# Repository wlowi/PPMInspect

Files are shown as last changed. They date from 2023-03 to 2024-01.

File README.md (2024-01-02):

# PPMInspect

Ein Tool zur Analyse von PPM Signalen.  

## Features

- PPM Decoder bis 16 Kanäle mit Anzeige der Timing Werte für jeden Kanal
- PWM Decoder
- Einfaches Voltmeter
- Oszilloskop mit 1kHz bis 100kHz Samplingrate
- Trigger (Freilaufend, ansteigende Flanke, abfallende Flanke)
- Zuschaltbares oversampling
- Einstellbarer Triggerlevel
- Triggerverzögerung bis 9900 Microsekunden.

Zur [Bedienungsanleitung](MANUAL.md)

## Handware

- 1 Arduino Nano
- 1 OLED Display 1.3" (SH1106 Controller)
- 3 Taster (RAFI Kurzhubtaster RACON 8 mit Stößel 7.5mm Höhe 8.2mm)
- 1 Z-Diode 4.7V
- 3 Widerstände 1/8 W 47k
- 2 Widerstände 1/8 W 100k
- 1 Elko 100uF 16V
- Stecker nach Wahl (Gebogene Pfostenleiste)

## Verwendete Libraries

Folgende Libraries werden benötigt und über die Arduino IDE installiert:

- SSD1306Ascii

## Arduino Nano Ports

- LCD SCK:   A5 (Port PC5 SCL)
- LCD SDA:   A4 (Port PC4 SDA)
- Taster 1:   5 (Port PD5 PCINT21 PCI2)
- Taster 2:   6 (Port PD6 PCINT22 PCI2)
- Taster 3:   7 (Port PD7 PCINT23 PCI2)
- Analog In: A3 (Port PC3)
- PPM In:     8 (Port PB0 ICP1)
- Vcc:       A0
   
## Timer

- Timer 0:     8 bit       Arduino micros() millis() delay()...
- Timer 1:    16 bit       PPM Timing (See PPM.cpp)

## Verzeichnisse

CAD - dxf und FreeCAD Model für ein Gehäuse  
doc - Zur Dokumentation  
PCB - KiCAD Schaltplan und Platinenlayout  
PPMGenerate_DELAY - PPM Test Generator mit Verzögerungsschleife  
PPMGenerate_ISR - PPM Test Generator über Interrupts  
PPMGenerate_PWM - PPM Test Generator über Hardware-PWM  
PPMInspect - Der Source Code  

## Und Sonst...

### Wird anstelle eines SH1106 ein SSD1306 Display Controller verwendet muss in PPMInspect.ino Zeile 98 von:

textUI.setDisplay(new TextUILcdSSD1306( &SH1106_128x64 )); \
geändert werden in: \
textUI.setDisplay(new TextUILcdSSD1306( &Adafruit128x64 ));

### Genauigkeit PPM Scan

- Servotiming pro Kanal: +/- 1 Microsekunde
- Puls: +/- 1 Microsekunde
- Frame: +/- 1 Microsekunde

## TODO

- Nix zur Zeit

## History

0.10.0: PWM Decoder\
0.9.17: User Interface aktualisiert\
0.9.16: PPM Erzeugung verbessert\
0.9.15: Frame Genauigkeit verbessert\
0.9.14: Min/max Werte im Voltmeter

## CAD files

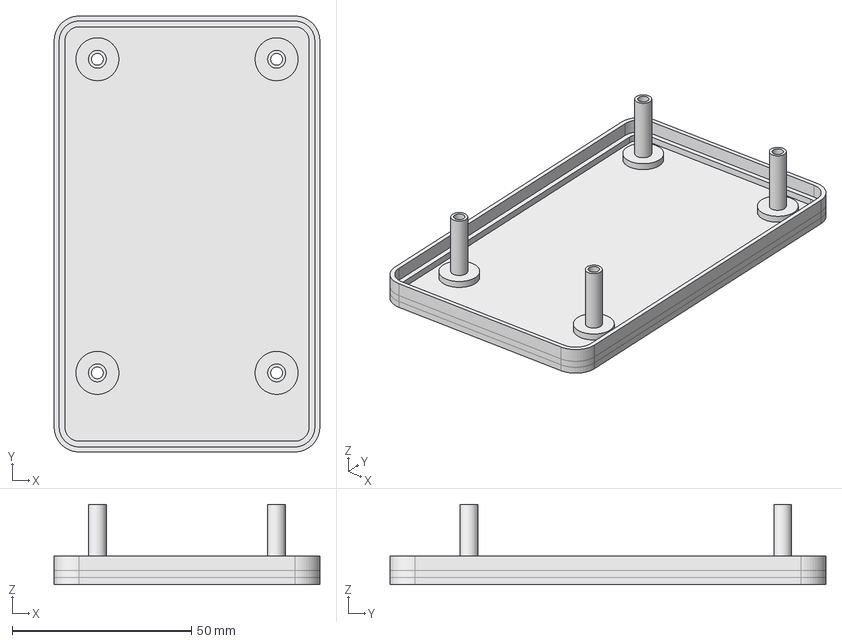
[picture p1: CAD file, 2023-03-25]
CAD/PPMInspectUnterschale.FCStd
74.1 x 121.7 x 22.4 mm

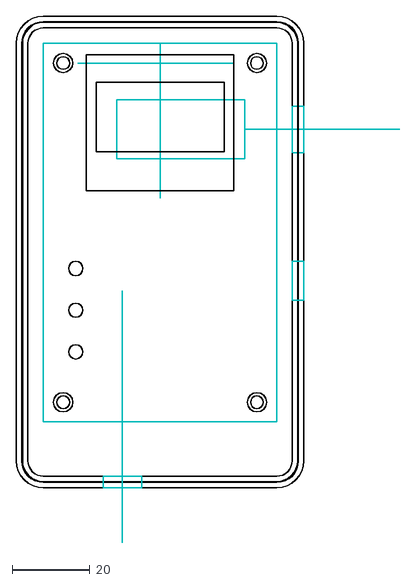
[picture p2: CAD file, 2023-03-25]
CAD/PPMInspect.dxf
98.9 x 135.8

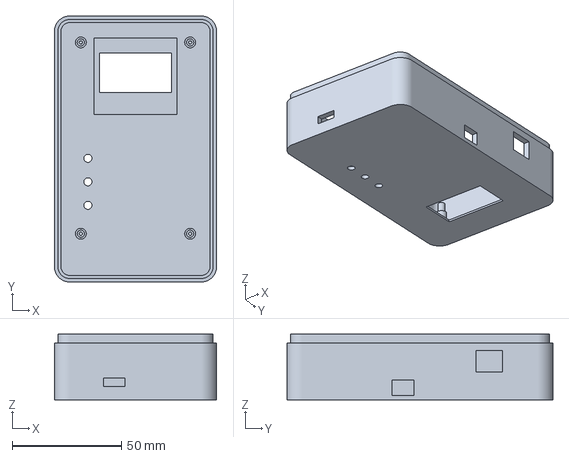
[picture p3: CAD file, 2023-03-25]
CAD/PPMInspectOberschale-Body.3mf
74.1 x 121.7 x 30.0 mm

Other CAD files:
CAD/PPMInspectUnterschale-Body.3mf
CAD/PPMInspectOberschale.FCStd
CAD/PPMInspectOberschale-Body.stl
CAD/PPMInspectUnterschale-Body.stl

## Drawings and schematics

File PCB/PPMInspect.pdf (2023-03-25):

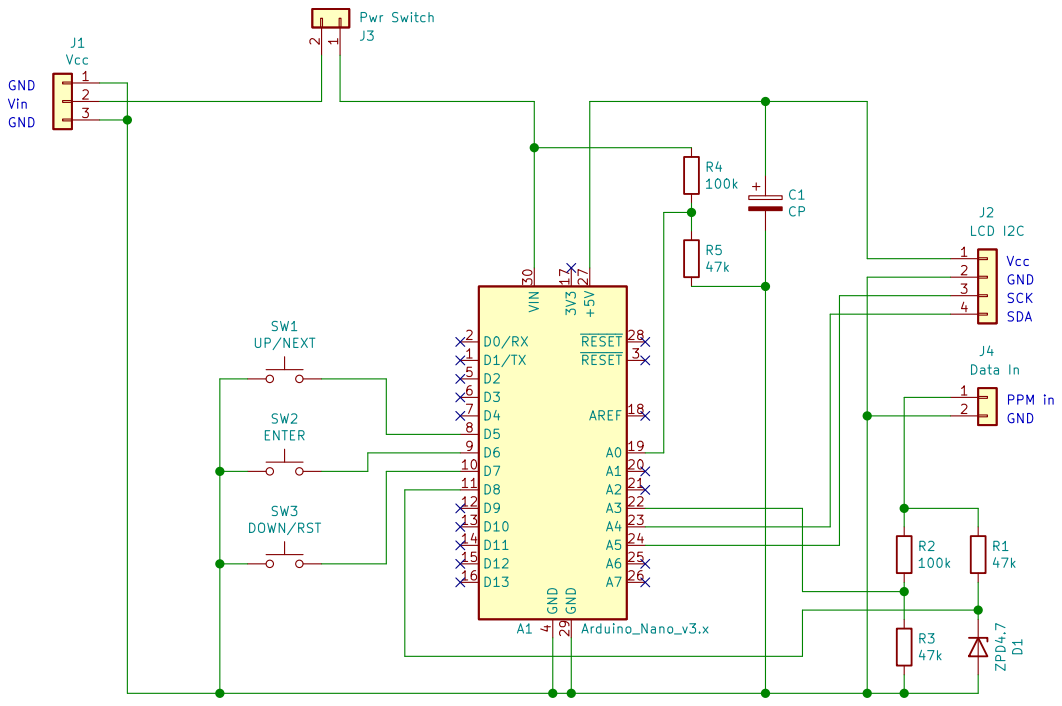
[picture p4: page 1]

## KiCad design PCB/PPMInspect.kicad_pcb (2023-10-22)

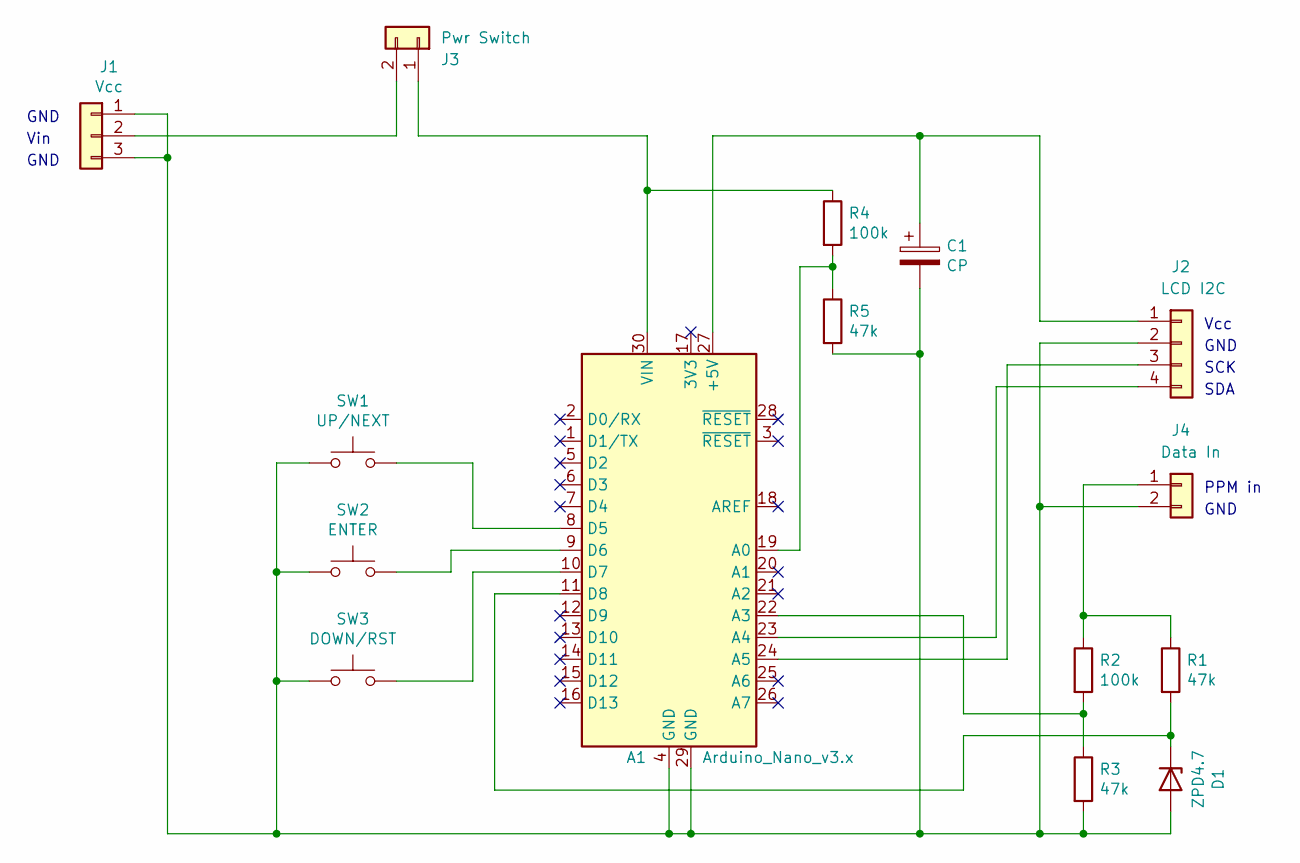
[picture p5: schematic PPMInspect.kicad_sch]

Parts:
A1: Arduino_Nano_v3.x; Arduino_Nano
C1: CP; CP_Radial_D6.3mm_P2.50mm
D1: ZPD4.7; D_DO-35_SOD27_P10.16mm_Horizontal
J1: Vcc; PinHeader_1x03_P2.54mm_Horizontal
J2: LCD I2C; PinSocket_1x04_P2.54mm_Vertical
J3: Pwr Switch; PinHeader_1x02_P2.54mm_Horizontal
J4: Data In; PinHeader_1x02_P2.54mm_Horizontal
R1, R3, R5: 47k; R_Axial_DIN0207_L6.3mm_D2.5mm_P10.16mm_Horizontal
R2, R4: 100k; R_Axial_DIN0207_L6.3mm_D2.5mm_P10.16mm_Horizontal
SW1: UP/NEXT; SW_PUSH_6mm
SW2: ENTER; SW_PUSH_6mm
SW3: DOWN/RST; SW_PUSH_6mm

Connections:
unnamed: A1.8 (D5), SW1.2
unnamed: A1.9 (D6), SW2.2
unnamed: A1.10 (D7), SW3.2
unnamed: A1.11 (D8), D1.1 (K), R1.2
unnamed: A1.19 (A0), R4.2, R5.1
unnamed: A1.22 (A3), R2.2, R3.1
unnamed: A1.23 (A4), J2.4
unnamed: A1.24 (A5), J2.3
unnamed: A1.27 (+5V), C1.1, J2.1
unnamed: A1.4 (GND), A1.29 (GND), C1.2, D1.2 (A), J1.1, J1.3, J2.2, J4.2, R3.2, R5.2, SW1.1, SW2.1, SW3.1
unnamed: A1.30 (VIN), J3.1, R4.1
unnamed: J1.2, J3.2
unnamed: J4.1, R1.1, R2.1

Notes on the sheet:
SDA
Vin
SCK
GND
PPM in
Vcc

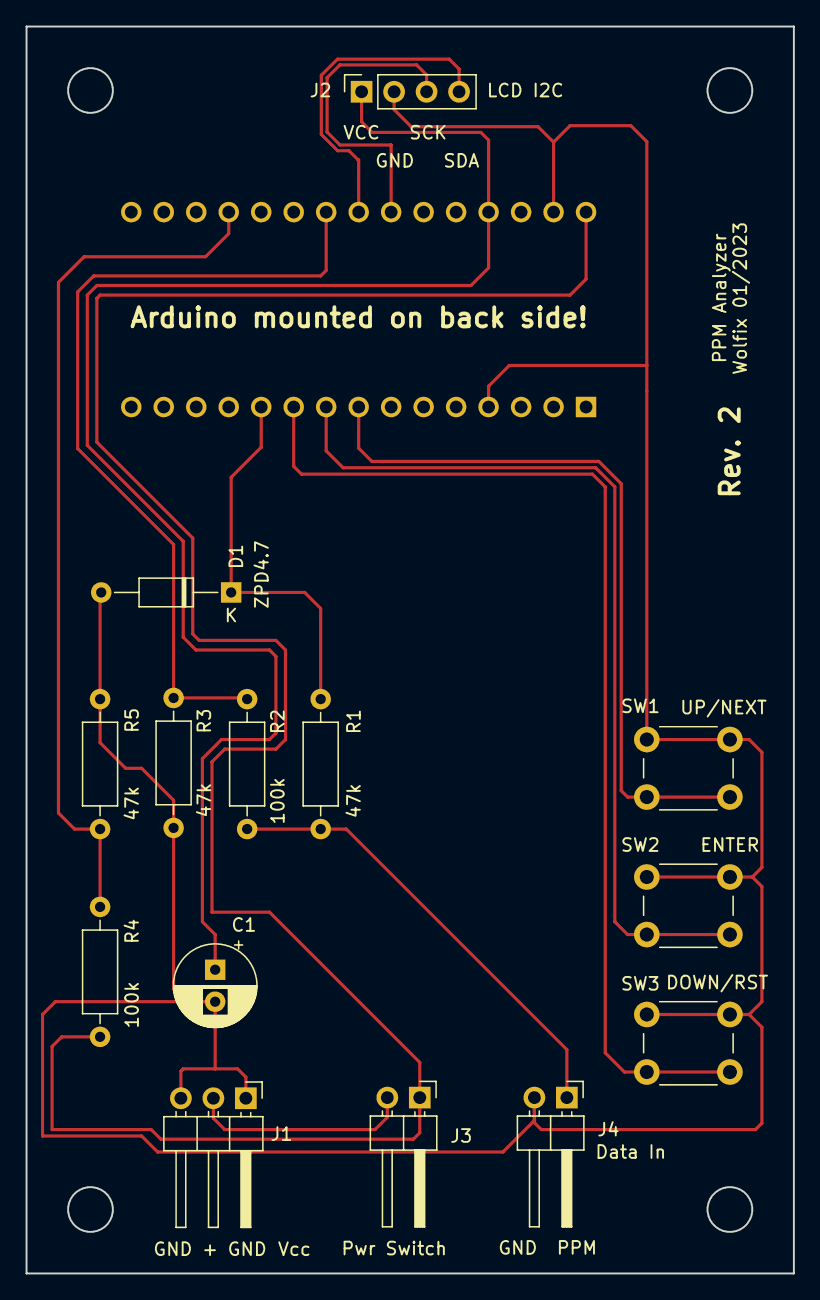
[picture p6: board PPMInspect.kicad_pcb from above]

Board: 2 copper layers, 60.0 x 97.5 mm, 15 parts (1 on the bottom side), 13 nets.

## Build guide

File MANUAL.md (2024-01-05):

# PPMInspect

Diese Anleitung beschreibt PPMInspect 0.10.3 (Januar 2024)

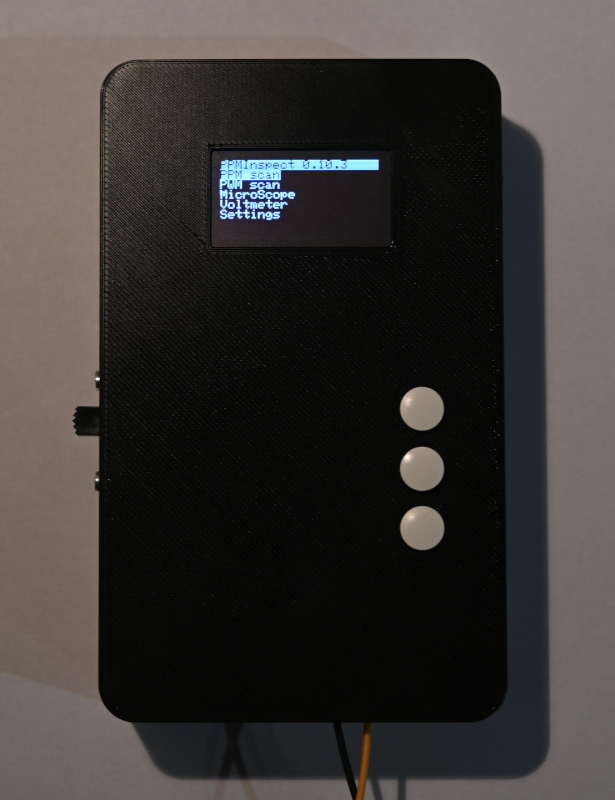
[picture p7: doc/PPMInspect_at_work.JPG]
AtWork


---
## Grundsätzliche Bedienung

Die Bedienung erfolgt über 3 Taster.
Die Taster unterscheiden einen kurzen und einen langen (> 250 MilliSekunden) Tastendruck. \
Wird der Taster länger als 1 Sekunde gedrückt gehalten wird die Funktion eines kurzen Tastendrucks automatisch wiederholt.

Taster 1:
- kurz:   UP
- lang:   RESET

Taster2:
- kurz:   ENTER
- lang:   CLEAR

Taster3:
- kurz:   DOWN
- lang:   OPTION

Seit Version 0.9.15 wird die Versorgungsspannung überwacht.\
Fällt die Spannung unter den in den Einstellungen eingestellten Wert, so wird im Display periodisch "Low Bat" angezeigt.

---
## Funktionstasten übersicht

### PPM Scan

- UP: Vorherige Zeile
- RESET: Sampling neu starten

- ENTER: Zur Kanalanzeige
- CLEAR: Zum Hauptmenü

- DOWN: Nächste Zeile
- OPTION: - 

### PPM Scan Kanalanzeige

- UP: Vorherige Zeile
- RESET: -

- ENTER: Zum PPM Scan
- CLEAR: Zum PPM Scan

- DOWN: Nächste Zeile
- OPTION: -

### PWM Scan

- UP: Vorherige Zeile
- RESET: Sampling neu starten

- ENTER: Zur grafischen PWM Anzeige
- CLEAR: Zum Hauptmenü

- DOWN: Nächste Zeile
- OPTION: -

### Grafische PWM Anzeige

- UP: Zum PWM Scan
- RESET: Wechsel "Servo" / "%" Modus

- ENTER: -
- CLEAR: Zum PWM Scan

- DOWN: Anzeige einfrieren
- OPTION: Gitter aus/ein

### MicroScope

- UP: Zum Hauptmenü
- RESET: -

- ENTER: MicroScope Einstellungen
- CLEAR: Zum Hauptmenü

- DOWN: Anzeige einfrieren
- OPTION:  Gitter aus/ein

### Voltmeter

- UP: Zum Hauptmenü
- RESET: Minimum/Maximum zurücksetzen

- ENTER: Zum Hauptmenü
- CLEAR: Zum Hauptmenü

- DOWN: Minimum/Maximum Ein/Aus
- OPTION: -

### Settings

- UP: Vorherige Zeile
- RESET: -

- ENTER: Einstellung ändern
- CLEAR: -

- DOWN: Nächste Zeile
- OPTION: -

---
## Funktionen

Im Hauptmenü wird die Funktion mit UP / DOWN ausgewählt und mit ENTER aufgerufen.

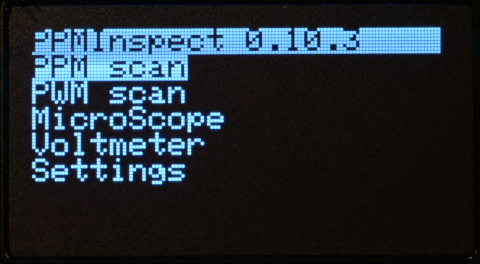
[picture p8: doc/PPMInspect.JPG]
Homescreen


---
## PPM Scan

Der PPM Scanner synchronisiert sich auf ein PPM Signal und zeigt die Signal Parameter an.

- Frame: Die Frame Länge in Microsekunden. Minimum und Maximum.
- Pulse: Die Pulslänge die jeden Kanal einleitet. Jeweils Minimum und Maximum, sowie die Puls Polarität.
- Level: Den Spannungslevel für LOW und HIGH in Volt.
- Frames: Die Anzahl der dekodierten Frames.

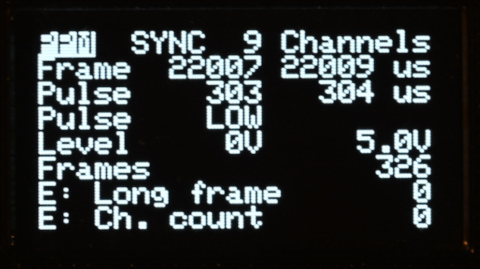
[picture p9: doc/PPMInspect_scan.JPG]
SCAN Scan


Mit CLEAR (langer Druck auf die ENTER Taste) wird in das Hauptmenu zurück gesprungen.

Mit RESET (langer Druck auf die UP Taste) werden alle Werte zurück gesetzt und neu synchronisiert.\
Mit der DOWN Taste kann nach unten gescrollt und weitere Parameter angezeigt werden.

- E: Long frames: Zu lange (verlorene) Frames
- E: Ch. count: Falsche Anzahl an Kanälen
- E: Pulse time: Puls Timing ausserhalb der Spezifikation (Siehe Einstellungen)

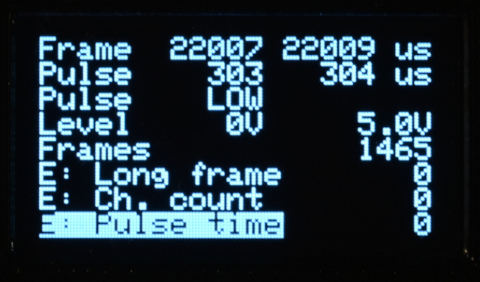
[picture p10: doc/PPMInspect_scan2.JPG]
SCAN Scan


Ein kurzer Druck auf ENTER wechselt zur Kanal Anzeige.\
Hier wird für jeden Kanal der letzte, der minimale und der maximale Timing Wert in Microsekunden angezeigt.\
Ein weiterer Druck auf ENTER wechselt zurück in die Scan Anzeige.

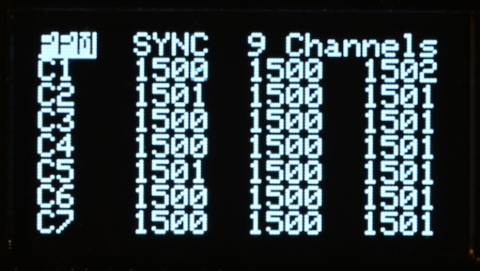
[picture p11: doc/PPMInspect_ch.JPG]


---
## PWM Scan

Der PWM Scanner zeigt die Eigenschaften einen PWM Signals an.

- Cyc.: Zykluszeit (H Puls + L Puls) in Microsekunden. Minimum und Maximum. 
- Pulse L: Zeit des letzten L Pulses.
- Pulse H: Zeit des letzten H Pulses.
- Duty Cyc.: Duty cycle. Prozentsatz des H Pulses an der Gesamtzeit.
- Freq.: Aktuelle PWM Frequenz
- Frames: Anzahl gescannter Frames
- Miss: Timer Überlauf. Kein Puls für 32 Millisekunden.

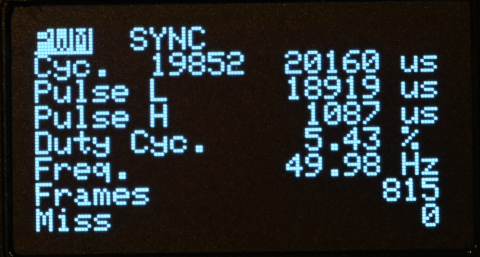
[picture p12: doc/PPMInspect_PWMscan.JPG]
PWMSCAN PWM Scan


Mit CLEAR (langer Druck auf die ENTER Taste) wird in das Hauptmenu zurück gesprungen.

Mit RESET (langer Druck auf die UP Taste) werden alle Werte zurück gesetzt und neu synchronisiert.

ENTER schaltet zu grafischen Anzeige um.

"PWM Servo" zeigt den Zeitwert des HIGH Pulses an. Der Wertebereich ist 900 - 2100 Microsekunden.

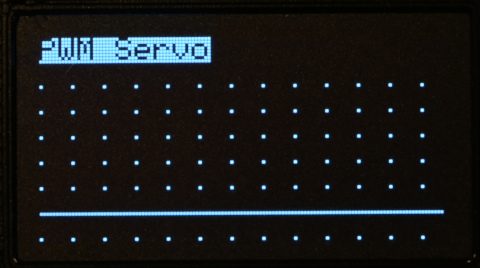
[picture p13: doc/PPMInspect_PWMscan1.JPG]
PWMSCAN PWM Scan


"PWM %" zeigt den Prozentsatz des H Pulses an der Gesamtzeit an.

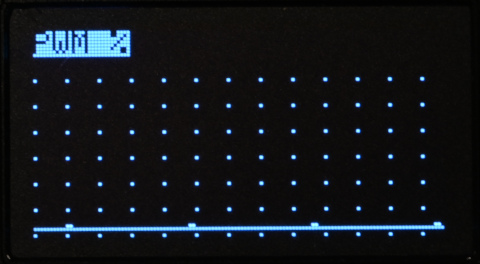
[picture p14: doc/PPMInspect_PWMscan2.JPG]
PWMSCAN PWM Scan


---
## MicroScope

Ein einfaches Oszillosop. (ACHTUNG: Nur positive Spannungen)

Mit ENTER wechselt man in die Oszilloskop Einstellungen.\
Folgende Werte können durch Drücken der UP / DOWN Tasten verstellt werden.  

- Samplingrate: Einstellbar zwischen 10 und 1000 Microsekunden (Entspricht 1 KHz bis 100 kHz)
- Oversampling: Siehe Oversampling
- Y Auflösung: 2V pro Einheit oder 1V pro Einheit.
- Triggermode: Einstellbar auf "f" freilaufend, "+" ansteigende Flanke, "-" abfallende Flanke
- Triggerlevel: in Volt
- Triggerverzögerung: Einstellbar zwischen 0 und 9900 Microsekunden. \
  Ein Trigger wird nur ausgelöst, wenn über diesen Zeitraum vorher kein weiterer Trigger gefunden wurde. \
  Damit wird der lange Sync Impuls ausgeblended und es wird immer auf den ersten Kanal getriggert. \
  Ein guter Wert für ein PPM Signal sind 2500 Microsekunden.

Mit UP oder CLEAR (langer Druck auf die ENTER Taste) wechselt man zurück in das Hauptmenü.

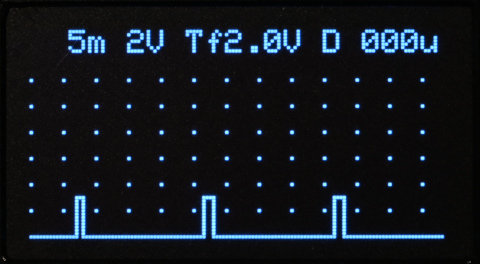
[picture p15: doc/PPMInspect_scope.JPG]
MicroScope1


Mit jedem neuen Datensatz wird der "Update" Marker ein/aus geschaltet.  
Das passiert im freilaufenden Modus und immer wenn ein Trigger anspricht.

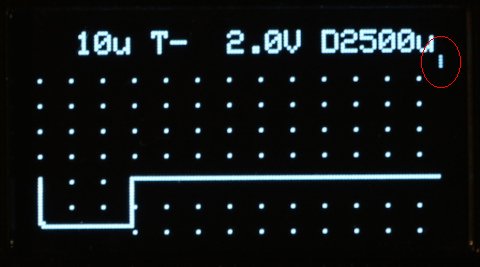
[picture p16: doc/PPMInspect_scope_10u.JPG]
MicroScope2


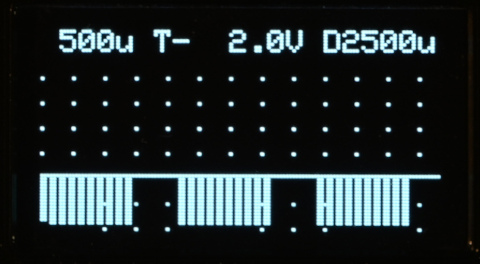
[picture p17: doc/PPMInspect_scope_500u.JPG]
MicroScope3


Oversampling mittelt den Wert eines Samples aus mehreren Messungen.\
Oversampling ist nicht immer erwünscht und muss daher explizit eingeschaltet werden.\
Es wird angezeigt durch ein "O" hinter der Samplingrate.

Oversampling is von der eingestellten Samplingrate abhängig.

- 10 und 20 Microsekunden: kein Oversampling
- 50 Microsekunden: 2 fach Oversampling
- 100 Microsekunden: 4 fach Oversampling
- \>= 200 Microsekunden: 8 fach Oversampling

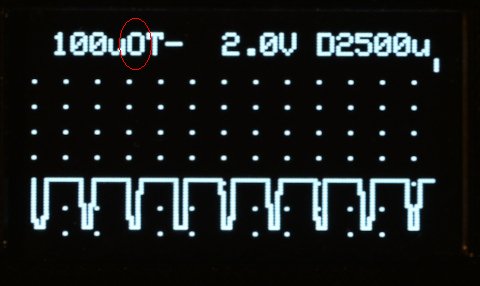
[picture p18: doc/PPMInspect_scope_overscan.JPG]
Overscan


Ein kurzer Druck auf die DOWN Taste friert die Anzeige ein. 

Ein langer Druck auf die DOWN Taste (OPTION) schaltet das Gitter ein und aus.\
Abstand der vertikalen Gitterlinien: 10 Samples.

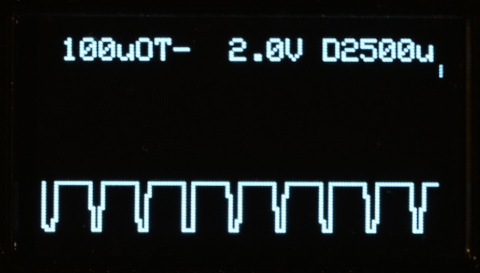
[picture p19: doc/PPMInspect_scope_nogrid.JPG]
NoGrid


---
## Voltmeter

Ein einfaches Voltmeter. (ACHTUNG: Nur positive Spannungen)

Seit Version 0.9.14 werden die gemessenen minimum und maximum Wert zusätzlich angezeigt.\
Ausserdem wurde die Samplefrequenz erhöht.

Ein Druck auf die DOWN Taste schaltet min/max aus und setzt die Samplefrequenz auf 2 Werte pro Sekunde herunter.
Ein langer Druck auf die UP Taste setzt die min/max Werte zurück.

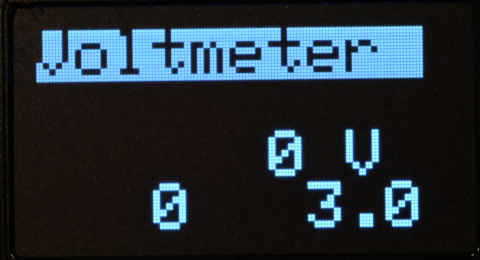
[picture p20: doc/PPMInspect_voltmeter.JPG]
Voltmeter


---
## Einstellungen

- Pulse min/max: Limits für das Puls Signal. Pulse ausserhalb der Limits werden als Fehler angezeigt.
- Servo min/max: Limits für Kanäle (Servos). 
- Sync min: Minimum Synchronisations Puls.

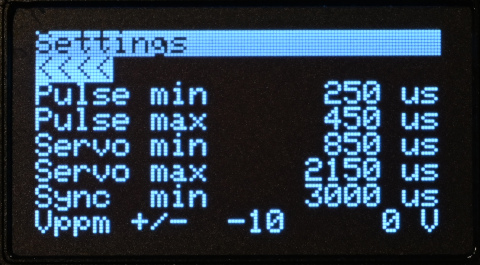
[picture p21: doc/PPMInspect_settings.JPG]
Settings1


- Vppm +/-: Kalibrierung der gemessenen Signalspannung.
- Vcc +/-: Kalibrierung der gemessenen Versorgungsspannung.
- Low Bat: Warnschwelle für die Versorgungsspannung.
- Memfree: Freier RAM Speicher in bytes. (Bei Programstart / minimum)

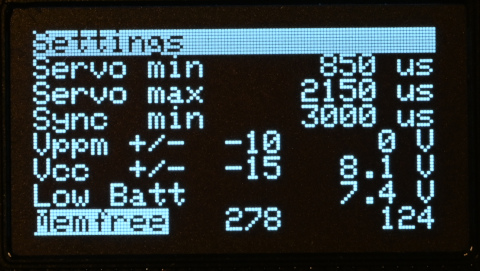
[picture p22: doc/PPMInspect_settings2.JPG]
Settings2


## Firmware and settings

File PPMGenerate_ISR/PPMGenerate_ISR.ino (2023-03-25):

/*
  PPMGenerate_ISR. A PPM generator for testing.

  MIT License

  Copyright (c) 2023 wlowi

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
  THE SOFTWARE IS PROVIDED "AS IS", WITHOUT WARRANTY OF ANY KIND, EXPRESS OR
  IMPLIED, INCLUDING BUT NOT LIMITED TO THE WARRANTIES OF MERCHANTABILITY,
  FITNESS FOR A PARTICULAR PURPOSE AND NONINFRINGEMENT. IN NO EVENT SHALL THE
  AUTHORS OR COPYRIGHT HOLDERS BE LIABLE FOR ANY CLAIM, DAMAGES OR OTHER
  LIABILITY, WHETHER IN AN ACTION OF CONTRACT, TORT OR OTHERWISE, ARISING FROM,
  OUT OF OR IN CONNECTION WITH THE SOFTWARE OR THE USE OR OTHER DEALINGS IN THE
  SOFTWARE.
*/

/*
 *      0  300     1100  1500  1900                22000
 *  ____     _______                 _____ ... ______
 *      |   |       |     |     |   |                |
 *      |___|       |     |     |___|                |
 *
 *      |   |
 *    PPM_SPACE
 *
 *      |---- PPM_MID ----|
 *
 *
 *  9 ch * 1.5 mSec = 13.5 mSec  SYNC = 22.0 - 13.5 = 6.5 mSec
 *
 */
 
#include <util/atomic.h>
#include <avr/sleep.h>
#include <avr/wdt.h>

#define PPM_CHANNELS        9
#define PPM_PIN             2


typedef uint8_t  channel_t;
typedef uint16_t timingUsec_t;

#define PPM_FRAME_usec      ((timingUsec_t)22000)
#define PPM_SPACE_usec      ((timingUsec_t)  300)
#define PPM_MID_usec        ((timingUsec_t) 1200)
#define PPM_RANGE100_usec   ((timingUsec_t)  400)
/* 150 % */
#define PPM_RANGEMAX_usec   ((timingUsec_t)  600)

#define PPM_MIN_usec        (PPM_MID_usec - PPM_RANGEMAX_usec)
#define PPM_MAX_usec        (PPM_MID_usec + PPM_RANGEMAX_usec)

/* Initial high for sync */
#define PPM_INIT_usec       ((timingUsec_t) 8000)

typedef struct ppmSet_t {

  timingUsec_t channel[ PPM_CHANNELS ];

} ppmSet_t;

ppmSet_t ppmSet;

/* PPM generation state machine state.
 * Used in the interrupt routine.
 */
static uint8_t outputState;

/* inFrameTime is used to compute the remaining time until frame end */
static timingUsec_t inFrameTime_usec;

static channel_t outputChannel;

/* Convert timer low, high values to microseconds.
 * Division by 2 is because the timer runs in 0.5 usec resolution.
 */
#define CONVERT_TIMER_TO_USEC( l, h)  ((((timingUsec_t)h << 8) + l) >> 1)

/* PPM generation state machine states */
#define BEGIN_OF_FIRST_SPACE    0
#define END_OF_SPACE            1
#define END_OF_MARK             2
#define END_OF_LAST_SPACE       4

#define H( v ) (uint8_t)((v >> 8) & 0xff)
#define L( v ) (uint8_t)(v & 0xff)


/* For performance we direct access port registers.
 */
static volatile uint8_t *out;   // ptr to data output reg
static volatile uint8_t *mode;  // ptr to data direction reg
static uint8_t pinbit;          // pin bitmask

#define PIN_LOW()  *out &= ~pinbit
#define PIN_HIGH() *out |= pinbit


/* This compensates time from begin of ISR to actual timer reset */
#define RESET_ADJUST (byte)6

/* This compensates ISR service time */
#define ISR_ADJUST   6

ISR( TIMER1_COMPA_vect) {

  timingUsec_t nextTimerValue_usec;
  uint8_t h, l;

  l = TCNT1L;
  h = TCNT1H;

  inFrameTime_usec = CONVERT_TIMER_TO_USEC( l, h);

  switch ( outputState) {
    case END_OF_SPACE:
      PIN_HIGH();
      nextTimerValue_usec = ppmSet.channel[outputChannel];
 
      outputState = END_OF_MARK;
      break;

    case END_OF_MARK:
      PIN_LOW();
      nextTimerValue_usec = PPM_SPACE_usec;

      outputChannel++;
      if ( outputChannel < PPM_CHANNELS)  {
        outputState = END_OF_SPACE; // repeat for next channel
      } else {
        outputChannel = 0;
        outputState = END_OF_LAST_SPACE; // done
      }
      break;

    case BEGIN_OF_FIRST_SPACE:
      PIN_LOW();
      TCNT1H = (byte)0;
      TCNT1L = RESET_ADJUST;
      nextTimerValue_usec = PPM_SPACE_usec;
      inFrameTime_usec = 0;
      
      outputState = END_OF_SPACE;
      break;

    case END_OF_LAST_SPACE:
      PIN_HIGH();
      nextTimerValue_usec = PPM_FRAME_usec - inFrameTime_usec;

      outputState = BEGIN_OF_FIRST_SPACE;
      break;

    default:
      nextTimerValue_usec = 0;
  }

  nextTimerValue_usec += inFrameTime_usec;
  /* Multiply by 2 because the timer resulution is 0.5 micro sec. */
  nextTimerValue_usec <<= 1;
  nextTimerValue_usec -= ISR_ADJUST;

  /* Set output compare register. HIGH BYTE FIRST ! */
  OCR1AH = H( nextTimerValue_usec);
  OCR1AL = L( nextTimerValue_usec);
}

void setup() {

  initPPM();
}

void loop() {

  set_sleep_mode( SLEEP_MODE_IDLE);
  cli();
  sleep_enable();
  sei();
  sleep_cpu();
  sleep_disable();
}

/* Initialization:
 *  - Set all channels to mid.
 *  - Switch PPM pin to output.
 *  - Initialize timer
 *      Timer 1 counts at a rate of 2Mhz ( 0.5 micro sec. )
 */
void initPPM() {

  ATOMIC_BLOCK( ATOMIC_RESTORESTATE) {

    for ( channel_t i = 0; i < PPM_CHANNELS; i++) {
      ppmSet.channel[i] = PPM_MID_usec;
    }

    inFrameTime_usec = 0;
    outputChannel = 0;
    outputState = BEGIN_OF_FIRST_SPACE;

    /* Set port line to output */
    uint8_t port = digitalPinToPort(PPM_PIN);
    out = portOutputRegister(port);
    mode = portModeRegister(port);
    pinbit = digitalPinToBitMask(PPM_PIN);
  
    *mode |= pinbit; // set pin to output

    PIN_HIGH();
  
    /* Don't use output compare pins */
    TCCR1A = (byte)0;
    /* Prescaler /8 = 2Mhz = 0.5 usec */
    TCCR1B = _BV(CS11);
    /* Set initial timer counter value */
    TCNT1H = (byte)0;
    TCNT1L = (byte)0;
    /* Set output compare register. HIGH BYTE FIRST ! */
    OCR1AH = H( PPM_INIT_usec );
    OCR1AL = L( PPM_INIT_usec );
    /* Enable output compare match A interrupt */
    TIMSK1 = _BV(OCIE1A);
  }
}

/* Set timing for a channel.
 *  
 * "value" must be between -1000 and 1000 for a PPM range of 100% (1100 - 1900 usec)
 * Larger values are clipped to 150% (900 - 2100 usec).
 */
void setChannelValue(int channel, int value) {

  timingUsec_t t;

  /* Convert:

     value
     =======
     CHANNELVALUE_MID   0
     CHANNELVALUE_MIN   -1250 == -125%  == -500
     CHANNELVALUE_MAX    1250 ==  125%  ==  500

     To:

     ppmTiming_t
     ===========
     PPM_MID_usec        ((timingUsec_t) 1200)
     PPM_MIN_usec        (PPM_MID_usec - PPM_RANGE_usec)
     PPM_MAX_usec        (PPM_MID_usec + PPM_RANGE_usec)

  */

  if ( channel < PPM_CHANNELS) {

    t = PPM_MID_usec + (value * 2 / 5);

    if ( t < PPM_MIN_usec) t = PPM_MIN_usec;
    if ( t > PPM_MAX_usec) t = PPM_MAX_usec;

    ATOMIC_BLOCK( ATOMIC_RESTORESTATE) {

      ppmSet.channel[ channel ] = t;

    }
  }
}

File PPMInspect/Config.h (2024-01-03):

/*
  PPMInspect. A PPM signal analysis tool.

  MIT License

  Copyright (c) 2023 wlowi

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
  THE SOFTWARE IS PROVIDED "AS IS", WITHOUT WARRANTY OF ANY KIND, EXPRESS OR
  IMPLIED, INCLUDING BUT NOT LIMITED TO THE WARRANTIES OF MERCHANTABILITY,
  FITNESS FOR A PARTICULAR PURPOSE AND NONINFRINGEMENT. IN NO EVENT SHALL THE
  AUTHORS OR COPYRIGHT HOLDERS BE LIABLE FOR ANY CLAIM, DAMAGES OR OTHER
  LIABILITY, WHETHER IN AN ACTION OF CONTRACT, TORT OR OTHERWISE, ARISING FROM,
  OUT OF OR IN CONNECTION WITH THE SOFTWARE OR THE USE OR OTHER DEALINGS IN THE
  SOFTWARE.
*/

#ifndef _Config_h_
#define _Config_h_

#include "Arduino.h"
#include "TextUI.h"

#define PPMINSPECT_VERSION "0.10.3"

#define ENABLE_MEMDEBUG

#ifdef ENABLE_MEMDEBUG

/* ATMega 328 p
 *
 *    0 -   31 Register File (32)
 *   32 -   95 Standard IO Memory (64)
 *   96 -  255 Extended IO Memory (160)
 *  256 - 2303 SRAM (2048)
 */

/* Start of free memory in SRAM */
#define freeStart memdebug[0]
/* Stackpointer */
#define stackLow memdebug[1]
/* Gap size or initial free bytes */
#define gapSize memdebug[2]
/* Free bytes determined by free space check */
#define gapFree memdebug[3]

/* Initialize every byte within the gap between
 * freeStart and stackLow with bit pattern 01010101
 */
#define MEMDEBUG_INIT()                       \
do {                                          \
    uint16_t i;                               \
    cli();                                    \
    gapFree = 0;                              \
    freeStart = (size_t)malloc( 1);           \
    stackLow = SPH << 8 | SPL;                \
    gapSize = stackLow - freeStart - 2;       \
    for( i=0; i<gapSize; i++) {               \
        *(byte*)(freeStart+i) = 0x55;         \
    }                                         \
    sei();                                    \
} while( false)

/* Check how many bytes are still free.
 * (Unchanged pattern 01010101)
 */
#define MEMDEBUG_CHECK()                      \
do {                                          \
    uint16_t i;                               \
    gapFree = 0;                              \
    for( i=0; i<gapSize; i++) {               \
        if( *(byte*)(freeStart+i) != 0x55) {  \
            break;                            \
        } else {                              \
            gapFree++;                        \
        }                                     \
    }                                         \
} while( false)

#endif

/* ================================================================== */

/* PPM */

#define PPM_MAX_CHANNELS           12
#define PPM_MIN_CHANNELS            4

#define PPM_MAX_PULSE              (2*PPM_MAX_CHANNELS +2)

#define PORT_PPM_IN                8
#define PORT_ANALOG_IN             A3
#define PORT_VCC                   A0

/* Interrupt mask for PORT_PPM_IN */
#define PORT_PPM_IN_PCINT_MASK     ((uint8_t)_BV(PCINT10))

/* ================================================================== */

/* Voltage mutliplied by 10 to maintain 1 fractional digits.
 * 50 = 5.00V
 */
#define ADC_VOLTAGE                50
/* 10 bits => 1024 steps */
#define ADC_VCC_RESOLUTION       1024

/* Voltage divider values in 1000Ohm units.*/
#define ADC_VOLTAGE_DIVIDER_R1    100
#define ADC_VOLTAGE_DIVIDER_R2     47

/* ================================================================== */

#define BUTTON_COUNT                3
#define BUTTON_PORTS          5, 6, 7
/* Actions for short press */
#define BUTTON_SHORT_KEYS      KEY_UP,    KEY_ENTER, KEY_DOWN
/* Actions for long press ( > 300 mSec ) */
#define BUTTON_LONG_KEYS       KEY_RESET, KEY_CLEAR, KEY_FUNCTION

/* ================================================================== */

/* Settings Default values */
#define PULSEVALIDMIN_usec        250
#define PULSEVALIDMAX_USEC        450
#define SERVOVALIDMIN_USEC        850
#define SERVOVALIDMAX_USEC       2150
#define SYNCVALIDMIN_usec        3000

/* ================================================================== */

typedef uint16_t checksum_t;

typedef struct config_t
{
    uint16_t pulseValidMin_usec;
    uint16_t pulseValidMax_usec;

    uint16_t servoValidMin_usec;
    uint16_t servoValidMax_usec;

    uint16_t syncValidMin_usec;

    int8_t   vppmAdjust;
    int8_t   vccAdjust;
    
    fixfloat1_t lowBattWarn;
    
    /* */

    checksum_t checksum;

} config_t;

#endif

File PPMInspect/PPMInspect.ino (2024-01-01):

/*
  PPMInspect. A PPM signal analysis tool.

  MIT License

  Copyright (c) 2023 wlowi

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
  THE SOFTWARE IS PROVIDED "AS IS", WITHOUT WARRANTY OF ANY KIND, EXPRESS OR
  IMPLIED, INCLUDING BUT NOT LIMITED TO THE WARRANTIES OF MERCHANTABILITY,
  FITNESS FOR A PARTICULAR PURPOSE AND NONINFRINGEMENT. IN NO EVENT SHALL THE
  AUTHORS OR COPYRIGHT HOLDERS BE LIABLE FOR ANY CLAIM, DAMAGES OR OTHER
  LIABILITY, WHETHER IN AN ACTION OF CONTRACT, TORT OR OTHERWISE, ARISING FROM,
  OUT OF OR IN CONNECTION WITH THE SOFTWARE OR THE USE OR OTHER DEALINGS IN THE
  SOFTWARE.
*/

/*
 *  PPMInspect
 *
 * Arduino Pro Micro port assignment
 * =================================
 *   LCD SCK    3
 *   LCD SDA    2
 *   Button 1  14
 *   Button 2  15
 *   Button 3  16
 *   Analog In  ?
 *   PPM In     ?
 *   Vcc       A0
 *   
 * Arduino Nano port assignment
 * ============================
 *   LCD SCK   A5 (Port PC5 SCL)
 *   LCD SDA   A4 (Port PC4 SDA)
 *   Button 1   5 (Port PD5 PCINT21 PCI2)
 *   Button 2   6 (Port PD6 PCINT22 PCI2)
 *   Button 3   7 (Port PD7 PCINT23 PCI2)
 *   Analog In A3 (Port PC3)
 *   PPM In     8 (Port PB0 ICP1)
 *   Vcc       A0
 *   
 * Timer
 * =====
 *   Timer 0   8 bit       Arduino micros() millis() delay()...
 *   Timer 1  16 bit       PPM Timing (See PPM.cpp)
 */

#include "Config.h"
#include "TextUI.h"

#include "TextUILcdSSD1306.h"
#include "TextUISimpleKbd.h"

#include "PPM.h"

#include "HomeScreen.h"
#include "DataScreen.h"
#include "PWMScreen.h"
#include "ScopeScreen.h"
#include "ChannelScreen.h"
#include "VMeterScreen.h"
#include "ConfigScreen.h"


#ifdef ENABLE_MEMDEBUG
size_t memdebug[4];
#endif


TextUI textUI(15);

extern PPM ppm;
extern config_t settings;

DataScreen dataScreen(ppm);
PWMScreen pwmScreen(ppm);
ScopeScreen scopeScreen(ppm);
ChannelScreen channelScreen(ppm);
VMeterScreen vMeterScreen(ppm);
ConfigScreen configScreen(ppm);

uint8_t buttons[BUTTON_COUNT] = { BUTTON_PORTS };
uint8_t skeys[BUTTON_COUNT] = { BUTTON_SHORT_KEYS };
uint8_t lkeys[BUTTON_COUNT] = { BUTTON_LONG_KEYS };

void setup()
{
    configScreen.load();

    textUI.setDisplay(new TextUILcdSSD1306( &SH1106_128x64 ));
    textUI.setInput(new TextUISimpleKbd(BUTTON_COUNT, buttons, skeys, lkeys));
    textUI.setReversedNav( true);

    textUI.setTimer(500);
    textUI.setHomeScreen(new HomeScreen());

#ifdef ENABLE_MEMDEBUG
    MEMDEBUG_INIT();
#endif
}

void loop()
{
    Event *e = textUI.getEvent();

    if( checkBattery(e)) {
        textUI.handle(e);
    }
    
#ifdef ENABLE_MEMDEBUG
    MEMDEBUG_CHECK();
#endif
}

/*
 * Check Battery.
 * Returns false on battery warning.
 */
bool checkBattery(Event *e)
{
    fixfloat1_t v;
    TextUILcd *lcd;
    static int8_t count = 0; // Counts timer timeouts (500msec)

    if( e->getType() == EVENT_TYPE_TIMER) {

        count++;
        
        if( count == 0) {
            // Switch back to regular display
            textUI.forceRefresh();
        
        } else if( count >= 20) { // 10 Seconds
            
            v = ppm.readVCC();
        
            if( v < settings.lowBattWarn ) {
                // Show battery warning
                lcd = textUI.getDisplay();
                lcd->clear();
                lcd->printStr( F("LOW BAT!"));
                count = -2;
                return false;
          
            } else { // Reset counter
                count = 0;
            }
        
        } else if( count < 0) {
            return false;
        }
    } else {
        if( count < 0) {
          return false;
        }
    }
    
    return true;
}

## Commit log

2023-03-26 Fix off by one in PPMGenerate_PWM.ino
    [PPMGenerate_PWM.ino]
2023-04-01 Voltmeter min/max. Vcc Monitor. V0.9.14
2023-04-08 Fixed unaccuracy in frame time computation. V0.9.15
    [PPM.cpp]
2023-04-19 Update to latest TextUI. Scope sample interval shortened. V0.9.17
    [Config.h, PPM.cpp, PPMInspect.ino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]
2023-10-22 Microscope grid fix. KiCad new version. V0.9.18
    [PPMInspect.kicad_pcb, PPMInspect.kicad_sch]
2024-01-01 PWM scan. V0.10.0
2024-01-02 PWM scope display. V0.10.2
2024-01-03 Remove freq from pwm set.
